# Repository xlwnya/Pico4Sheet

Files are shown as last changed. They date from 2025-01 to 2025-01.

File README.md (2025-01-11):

# Pico4Sheet
ContactSheet( https://store.diver-x.jp/products/contactsheet )をPico4のコントローラで使用するためのフレキ基板&筐体設計データ
* Pico4Ultraについてはトラッキングセンサ位置に干渉する可能性があるため、干渉を避けるための設計変更が恐らく必要です。

## 現状
* とりあえず使用可能です。
* センサ配置の都合上 筐体の下部を覆うため電池の取り外し時等にコントローラから外す必要あります。
* 接点の配置の問題か、現在の設計では中指が立ちやすいです。導電性のあるテープ等により接点を延長すると改善します。
* 筐体の構造のみではコントローラに十分固定できないため、両面テープ等により追加で固定が必要です。
  * 私は ニチバン 両面テープ ナイスタック (粗面) NW-P15SF を小さめに切って、さらに少し粘着力を落とした上で使用しています。

## FlexGerber
* タッチセンサ用フレキ基板のガーバーファイルです。左右それぞれをjlcpcbで製造を行う想定です。
  * EasyEDA Pro で作成したデータです 基板設計: https://oshwlab.com/xlwnya/pico4sheet
  * FlexGerber/Gerber_Pico4Sheet_2L_2024-09-26.zip 左用
  * FlexGerber/Gerber_Pico4Sheet_2R_2024-09-26.zip 右用
* 割引の関係上、左右それぞれの注文を別々に行う必要があります。
* 製造設定
  * Gold Fingers: Yes
  * Gold Fingers Thickness: 0.3mm
  * EDA Software: Other (実際のところファイル自体はEasyEDA Proで作成されていますが、その場合少量(5枚)での特別価格($2)が適用されないためOtherにする必要があります(サポートにOtherと指定しても問題ないことは確認済))
  * Stiffener: polyimide
  * Polyimide Thickness: 0.25mm
  * Mark on PCB: Remove Mark

## Model
* 筐体データです。
* "Pico 4 controller 3D scan" by LWC (CC by 4.0) https://www.printables.com/model/300620-pico-4-controller-3d-scan
  のデータを元に作成されています。
  * スキャンデータは僅かに実際のコントローラより大きかったため縮小しています。
  * コントローラを覆うようにメッシュを生成して、コントローラに取り付けられる構造を作成しています。
  * 筐体がコントローラを挟めるように横方向を95%に縮小しています。
  * 以上をベースとして筐体部分等を追加しています。
* Pico4Sheet_v7.rsdocx, Pico4Sheet_v7.stp
  * 設計データです。作成中のデータについては訳が分からない状態になっているためほぼ完成データのみです。
* stl
  * 3Dプリント用データです。
  * v7でFFF式の3Dプリンタで印刷しやすいように修正されました。ビルドプレートとの接地面積確保のため多少角ばっています。
* フタのねじはM1.7 x 5mmのタッピングねじを使用しています。
* 現状の問題点
  * ボタンの穴が小さいためオリジナルのボタン部品は入らない状態です。
  * フタの構造はあまりちゃんとした形になっていません。(実際のところフタは必要ではないです)
  * フタのみでは基板およびバッテリーの固定に不十分なためテープ等で固定する必要があります。
  * 基板のUSB端子部分はプリント時の誤差により入りにくい可能性があります(恐らく曲げるなどをすると入ります)
  * 中指の接点が小さめのため、中指がまっすぐになりやすいです。導電性のテープで中指の接点を延長することで改善できます。

## 使用方法
* 筐体にフレキ基板を両面テープで貼り付ける。
  * Grip部分から貼ると多少位置合わせしやすいです。
  * 接点位置は手のサイズに合わせて変更した方が良い可能性があります。
* フレキ基板のFPC部分を折り畳んで位置調整がしやすいようにする。(あまり位置調整はできていないので基板のコネクタに対して少し斜めです)
* ContactSheetの基板、絶縁用の板、電池をテープ等でまとめた上で基板のコネクタにフレキ基板を差し込んで固定する。
  * コネクタの黒い部分をFPC側に引いてスライドすると固定が外れる仕組みになっています。
  * 接触が悪いと指が一部動かなくなります。
* 基板を筐体に固定する。
  * USB端子部分を凹みの部分に引っかけると固定されます。
  * テープ等で追加で固定を行なった方が良いです。
* フタを付けて固定する(任意)
  * M1.7 x 5mm のタッピングねじを使用することで固定できるはずです。

## 組み立て例
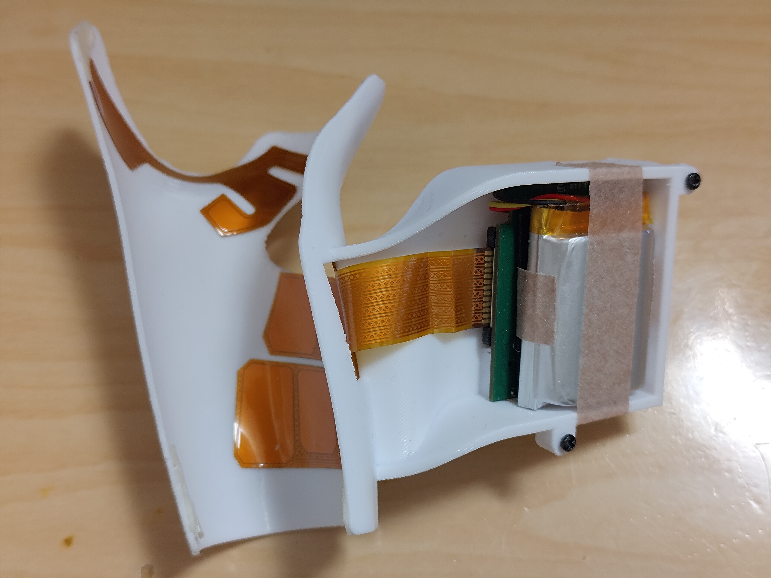
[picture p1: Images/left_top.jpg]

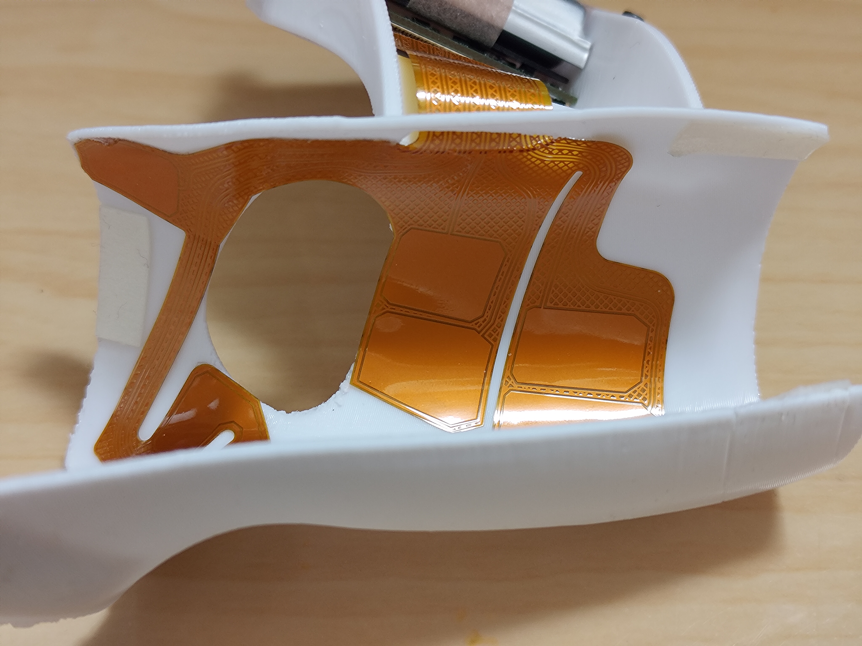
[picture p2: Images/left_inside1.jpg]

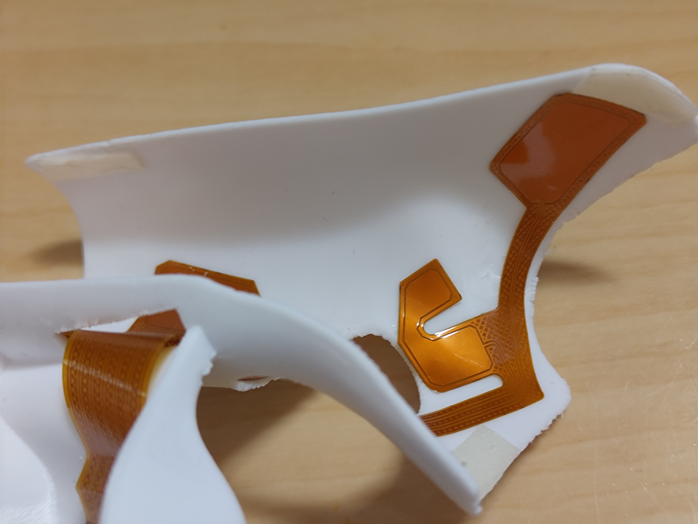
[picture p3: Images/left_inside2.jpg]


中指の接点を導電性のテープ等で延長することで中指のトラッキングを良くすることができます。

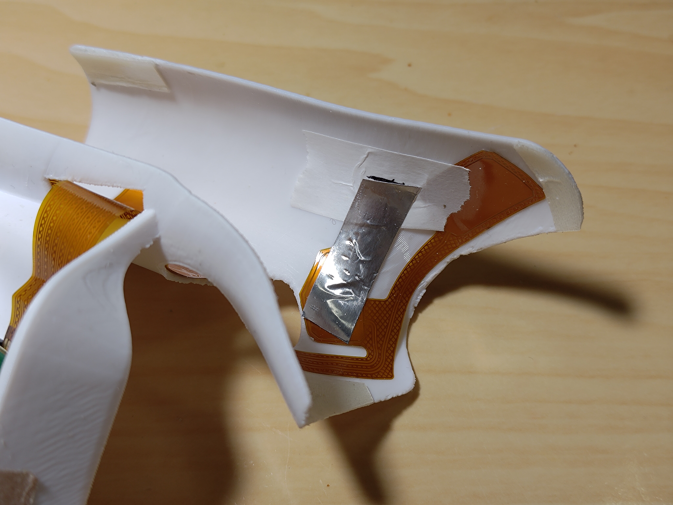
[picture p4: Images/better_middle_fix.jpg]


## License
* Modelについて、"Pico 4 controller 3D scan" by LWC (CC by 4.0) https://www.printables.com/model/300620-pico-4-controller-3d-scan
  のデータを元に作成されているため、CC by 4.0 が適用されます。
* 他の部分についても CC by 4.0 とします。

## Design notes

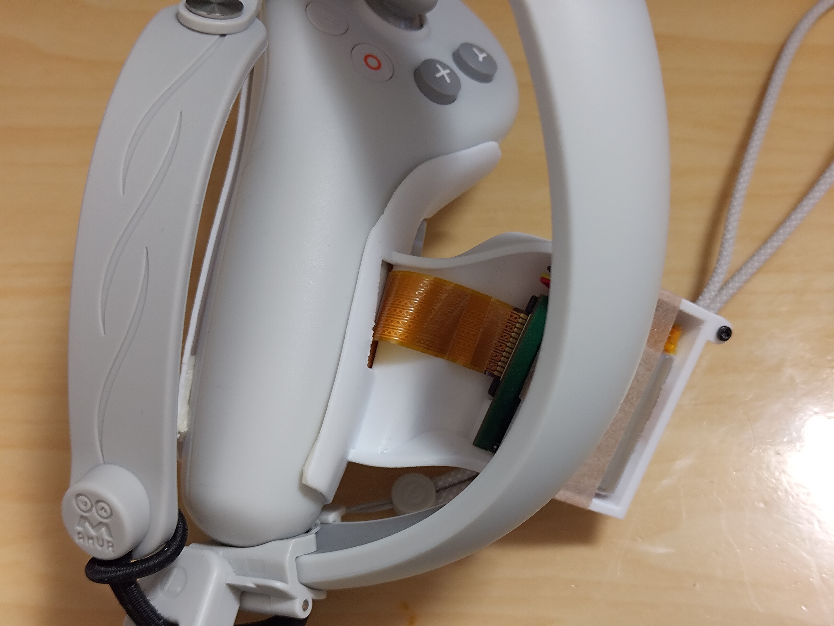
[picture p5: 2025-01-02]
Images/attached1.jpg

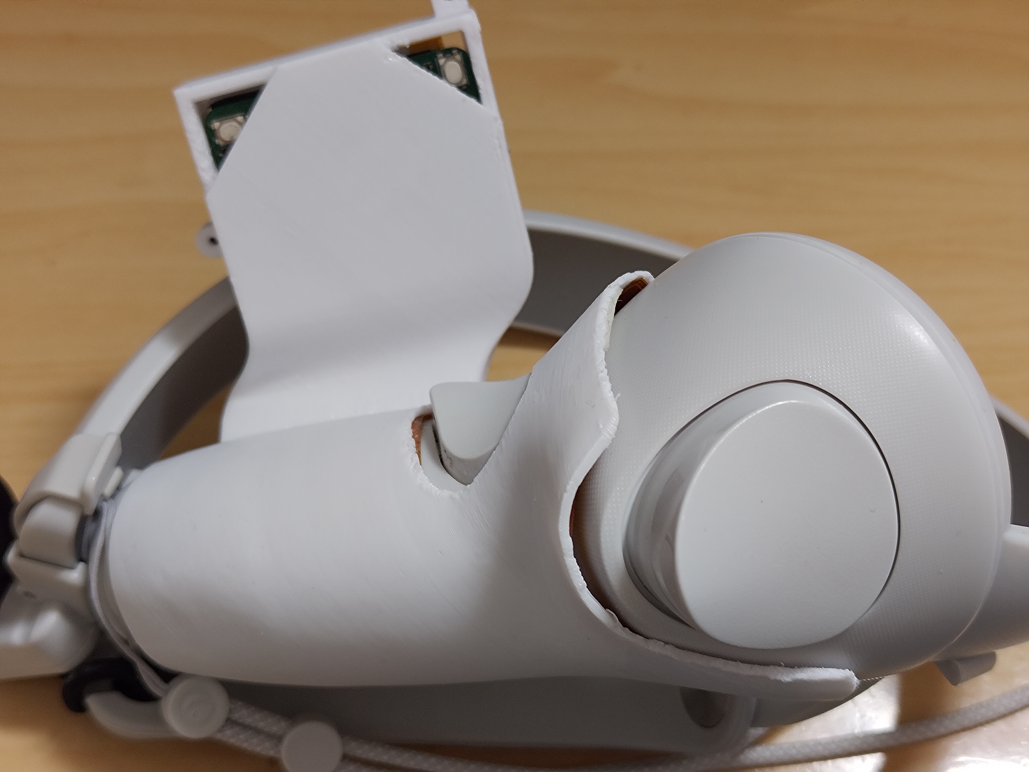
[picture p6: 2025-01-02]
Images/attached2.jpg

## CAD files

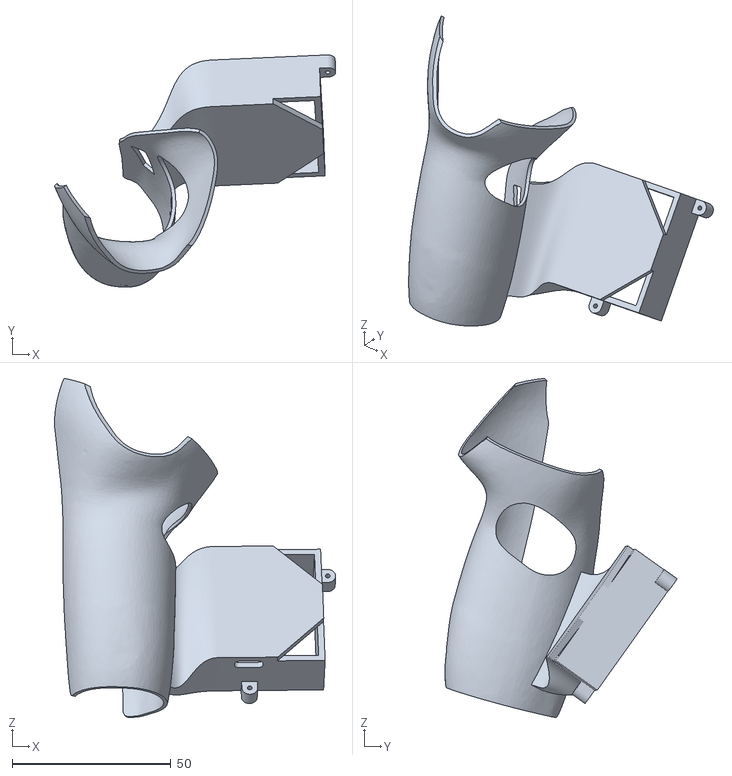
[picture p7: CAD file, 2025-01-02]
Model/stl/Pico4Sheet_v7_R.stl
88.6 x 73.1 x 106.7

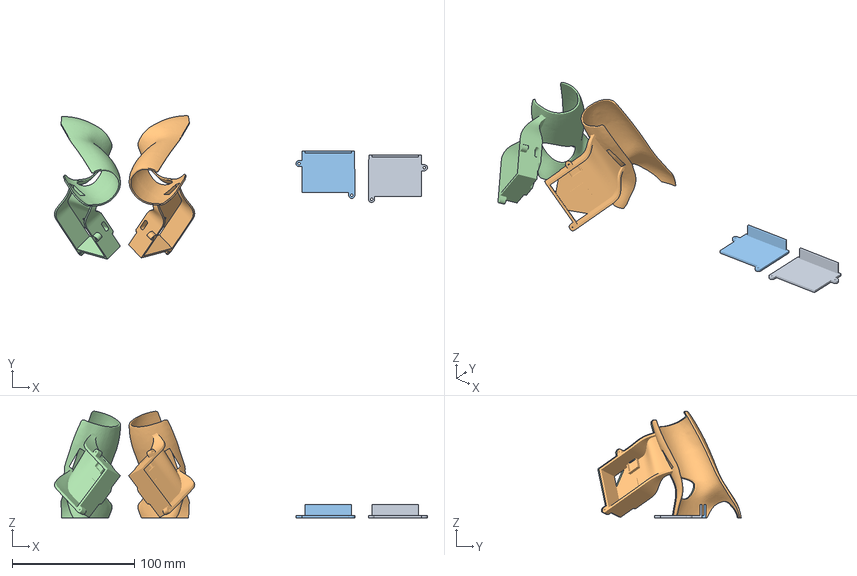
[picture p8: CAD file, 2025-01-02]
Model/stl/Pico4Sheet_v7.3mf
304.6 x 117.3 x 87.1 mm
Pico4Sheet_v6_Futa5L.stl
Pico4Sheet_v7_L.stl
Pico4Sheet_v6_Futa5R.stl
Pico4Sheet_v7_R.stl

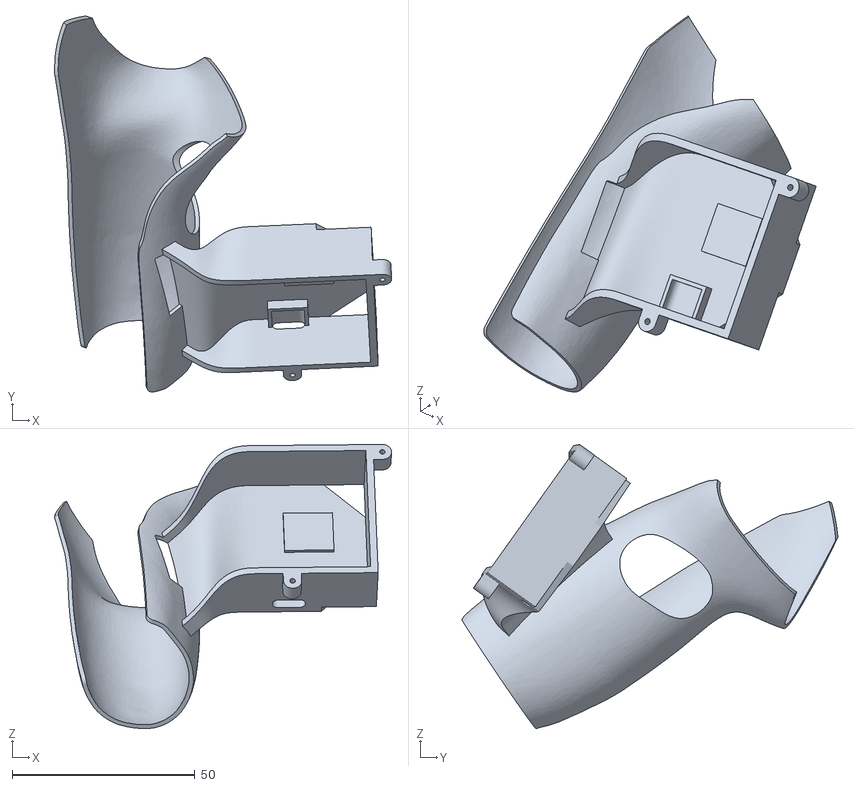
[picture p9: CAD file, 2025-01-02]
Model/stl/Pico4Sheet_v7_L.stl
92.1 x 102.7 x 77.6

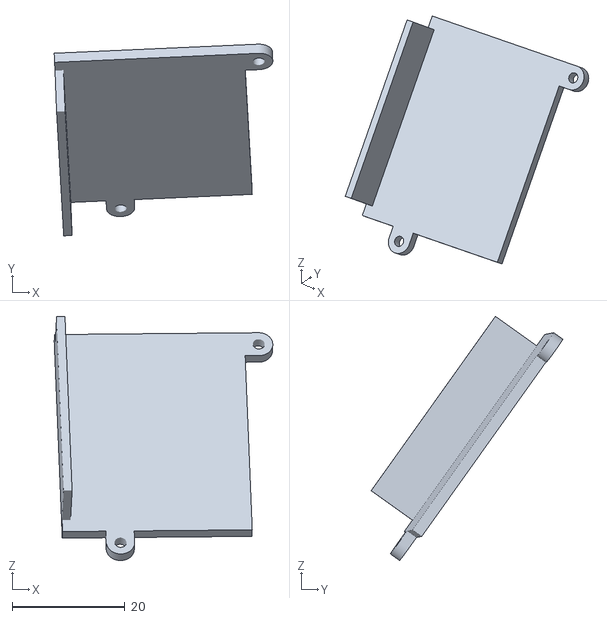
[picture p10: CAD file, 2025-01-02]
Model/stl/Pico4Sheet_v6_Futa5R.stl
38.8 x 34.1 x 43.3

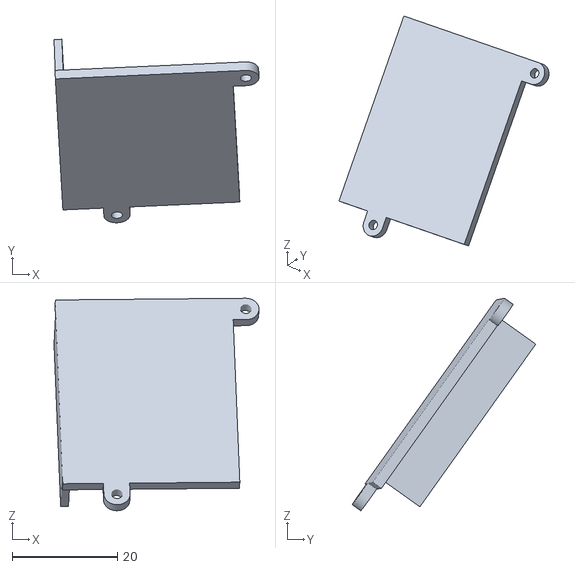
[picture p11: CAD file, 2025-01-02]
Model/stl/Pico4Sheet_v6_Futa5L.stl
39.0 x 35.0 x 40.5

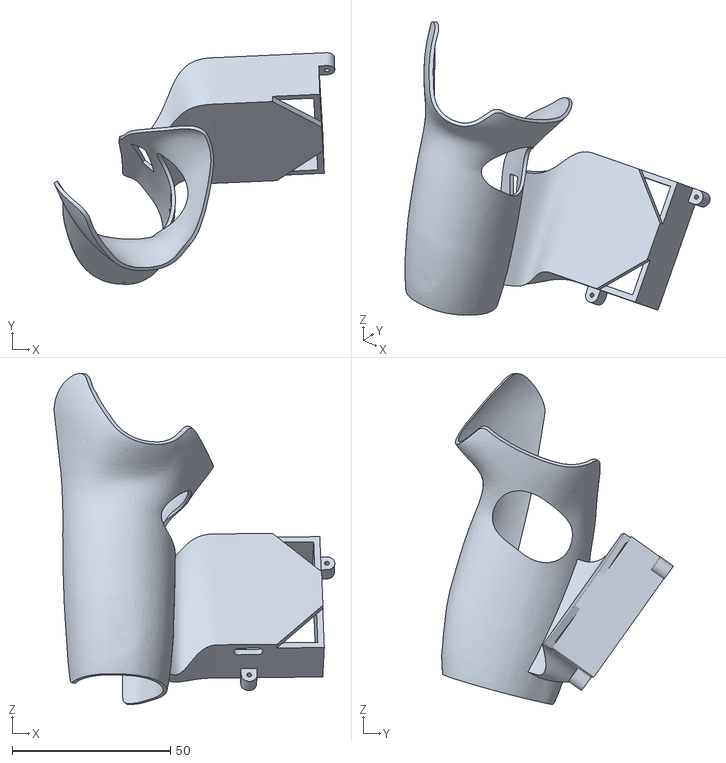
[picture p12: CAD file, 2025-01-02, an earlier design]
Model/stl/Pico4Sheet_v6_R.stl
88.6 x 73.1 x 104.5

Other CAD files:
Model/stl/Pico4Sheet_v6_L.stl

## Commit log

2025-01-02 Model data (based on "Pico 4 controller 3D scan" by LWC https://www.printables.com/model/300620-pico-4-controller-3d-scan)
2025-01-02 画像追加
2025-01-02 model v7 (FFF 3DP friendly)
    [Pico4Sheet_v6.3mf, Pico4Sheet_v7.3mf, Pico4Sheet_v7_L.stl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]
2025-01-11 add middle finger fix image
